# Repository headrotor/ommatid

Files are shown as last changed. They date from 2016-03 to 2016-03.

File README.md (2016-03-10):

# ommatid

Code and design files for my Ommatid spherical display/sensor array. 

* Here's an [Instructable about the enclosure and dome fabrication](http://www.instructables.com/id/Ommatid-Spherical-Display-constructing-the-enclosu/)
* Here's an [Instructable about the electronics and software](http://www.instructables.com/id/Ommatid-Spherical-Display-Electronics-Programming-/)

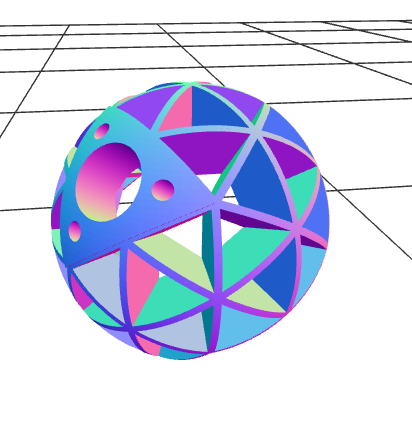
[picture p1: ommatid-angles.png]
cad rendering of sphere bottom section Ommatid CAD


Here are the construction and code files:

* `cad` -- 3D cad files. Likely not so useful unless you have access to a Stratasys Objet 
* `PCB` -- Schematic and printed circuit board design files
* `firmware` -- C code for ATTiny firmware for PCBs
* `code` -- host code (Python) for Ommatid.
* `sim` -- simulator, in [processing.org](http://processing.org) Python environment

NB: code is still very much a work in progress!

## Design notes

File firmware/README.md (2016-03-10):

# ommatid -- CAD files

Firmware for the Ommatid spherical display/sensor array. 

* Here's an [Instructable about the enclosure and dome fabrication](http://www.instructables.com/id/Ommatid-Spherical-Display-constructing-the-enclosu/)
* Here's an [Instructable about the electronics and software](http://www.instructables.com/id/Ommatid-Spherical-Display-Electronics-Programming-/)

This is C code designed to be executed on the 19 triangular boards inside the Ommatid. Each board has an ATTiny microcontroller, four independent IR LEDs and corresponding IR photodarlingtons (to sense reflected IR), and four WS2812B RGB LEDs. Note the RGB LEDs are not controlled or even connected to,  the ATTtiny).

All 19 boards are connected to the same RS-485 serial line at 250000
baud. Boards communicate with the host using a "speak only when spoken
to" protocol to eliminate bus contention.  Each board has an address
and will respond only to serial commands where it has been
specifically addressed. Addresses are one-byte ASCII characters from
a-o inclusive.

Serial protocol documentation: forthcoming!

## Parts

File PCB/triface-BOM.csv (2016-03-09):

Part | "Value" | "Device" | "Package" | "Description" | "COLOR" | "TP_SIGNAL_NAME"
+5V | "TEMT1020" | "TEMT1020" | "TEMT1020" | "" | "" | ""
C1 | "10uF" | "C-EUC0805" | "C0805" | "CAPACITOR | European symbol" | "" | ""
C2 | "10uF" | "C-EUC0805" | "C0805" | "CAPACITOR | European symbol" | "" | ""
C3 | "10uF" | "C-EUC0805" | "C0805" | "CAPACITOR | European symbol" | "" | ""
CX0 | "22pF" | "C-EUC0603" | "C0603" | "CAPACITOR | European symbol" | "" | ""
CX1 | "22pF" | "C-EUC0603" | "C0603" | "CAPACITOR | European symbol" | "" | ""
IC1 | "75ALS176AD" | "75ALS176AD" | "SO-08" | "DIFFERENTIAL BUS TRANSCEIVERS" | "" | ""
L1 | "WS2812B" | "WS2812B" | "WS2812B" | "" | "" | ""
L2 | "WS2812B" | "WS2812B" | "WS2812B" | "" | "" | ""
L3 | "WS2812B" | "WS2812B" | "WS2812B" | "" | "" | ""
L4 | "WS2812B" | "WS2812B" | "WS2812B" | "" | "" | ""
LED1 | "LG_T679-E1F1-1" | "LG_T679-E1F1-1" | "PLCC2" | "LC TOPLED® Low Current LED" | "green" | ""
LED2 | "LG_T679-E1F1-1" | "LG_T679-E1F1-1" | "PLCC2" | "LC TOPLED® Low Current LED" | "green" | ""
LED3 | "" | "LED0603" | "LED-0603" | "LEDs" | "" | ""
LED4 | "LG_T679-E1F1-1" | "LG_T679-E1F1-1" | "PLCC2" | "LC TOPLED® Low Current LED" | "green" | ""
LED5 | "LG_T679-E1F1-1" | "LG_T679-E1F1-1" | "PLCC2" | "LC TOPLED® Low Current LED" | "green" | ""
Q1 | "" | "MOSFET-NREFLOW" | "SOT23" | "N-Channel Mosfet" | "" | ""
Q2 | "" | "MOSFET-NREFLOW" | "SOT23" | "N-Channel Mosfet" | "" | ""
Q3 | "" | "MOSFET-NREFLOW" | "SOT23" | "N-Channel Mosfet" | "" | ""
Q4 | "" | "MOSFET-NREFLOW" | "SOT23" | "N-Channel Mosfet" | "" | ""
R1 | "2.2K" | "R-US_R0603" | "R0603" | "RESISTOR | American symbol" | "" | ""
R2 | "100" | "R-US_R0805" | "R0805" | "RESISTOR | American symbol" | "" | ""
R3 | "100" | "R-US_R0805" | "R0805" | "RESISTOR | American symbol" | "" | ""
R4 | "2.2K" | "R-US_R0603" | "R0603" | "RESISTOR | American symbol" | "" | ""
R5 | "2.2K" | "R-US_R0603" | "R0603" | "RESISTOR | American symbol" | "" | ""
R6 | "2.2K" | "R-US_R0603" | "R0603" | "RESISTOR | American symbol" | "" | ""
R7 | "330" | "R-US_R0603" | "R0603" | "RESISTOR | American symbol" | "" | ""
RLED1 | "330" | "RESISTOR0603-RES" | "0603-RES" | "Resistor" | "" | ""
T1 | "TEMT1020" | "TEMT1020" | "TEMT1020" | "" | "" | ""
T2 | "TEMT1020" | "TEMT1020" | "TEMT1020" | "" | "" | ""
T3 | "TEMT1020" | "TEMT1020" | "TEMT1020" | "" | "" | ""
U$1 | "ATTINY1634" | "ATTINY1634" | "SOIC20" | "" | "" | ""
Y1 | "12MHz" | "CRYSTAL5X3" | "CRYSTAL-SMD-5X3" | "Various standard crystals. Proven footprints. Spark Fun Electronics SKU : COM-00534" | "" | ""

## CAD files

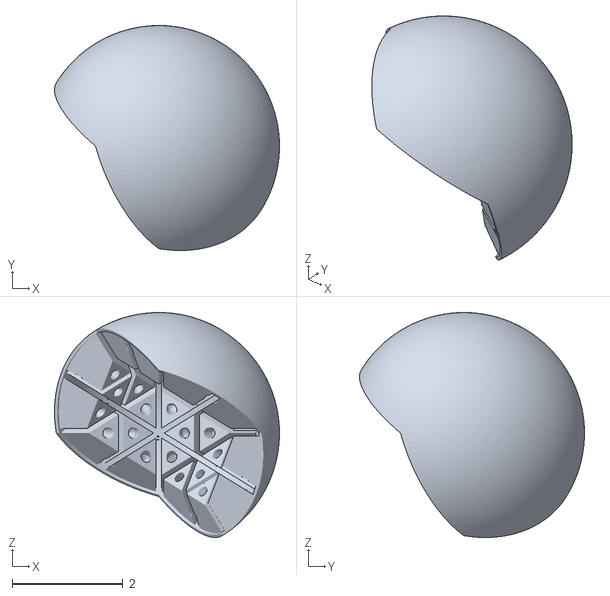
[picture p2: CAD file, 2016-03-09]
cad/top_dome_trans_2.stl
4.06 x 4.06 x 4.06

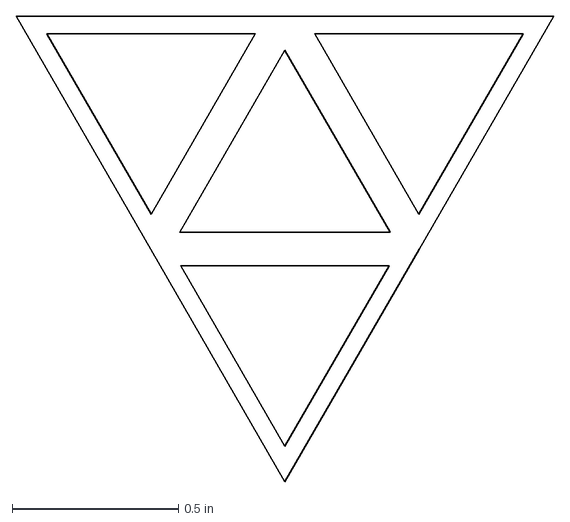
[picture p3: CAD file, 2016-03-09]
PCB/interiorface.dxf
1.62 x 1.40 in

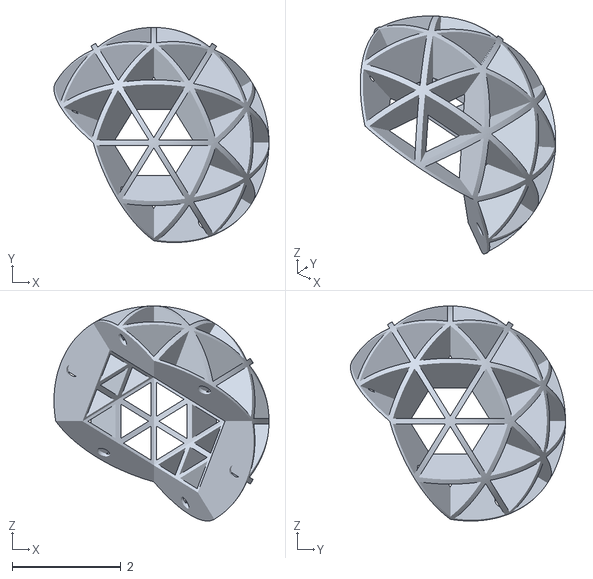
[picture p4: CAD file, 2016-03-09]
cad/top_dome_opaque_2.stl
3.95 x 3.95 x 3.95

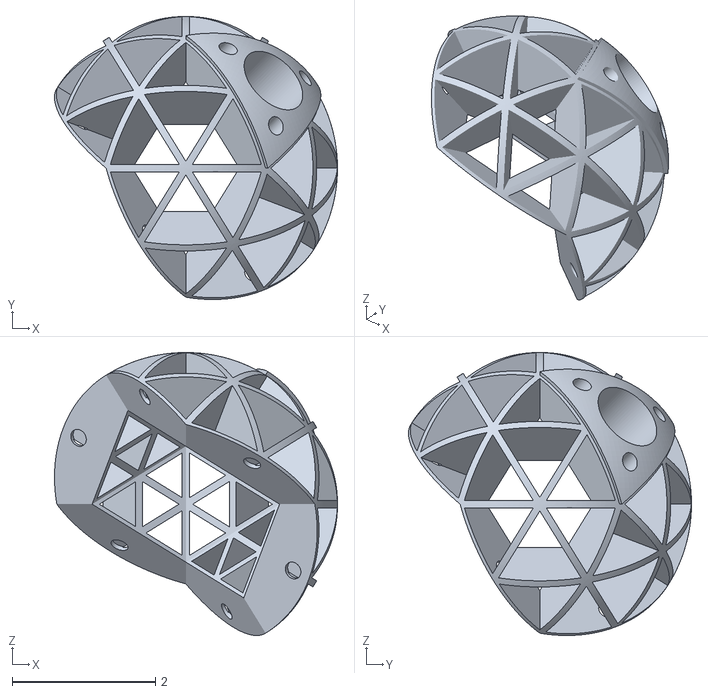
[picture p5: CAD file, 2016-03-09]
cad/bottom_dome_opaque_2.stl
3.95 x 3.95 x 3.95

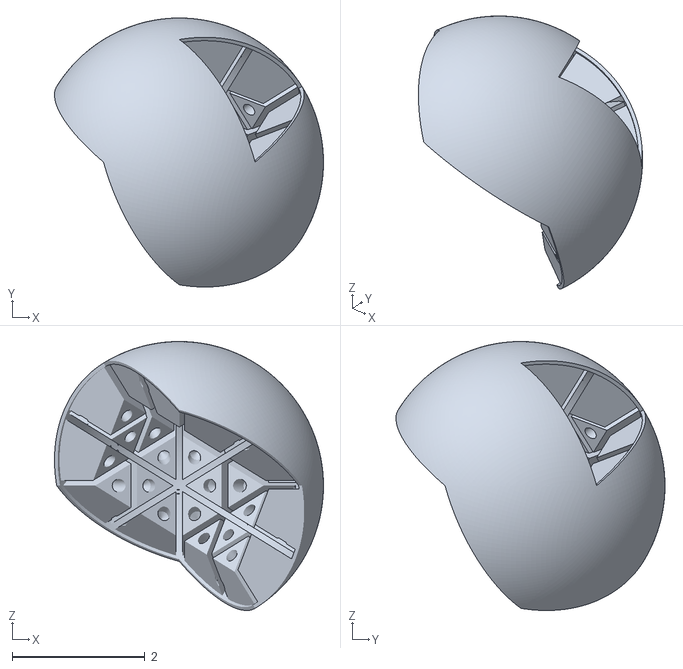
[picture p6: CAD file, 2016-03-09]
cad/bottom_dome_trans_2.stl
4.06 x 4.06 x 4.06

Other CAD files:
cad/sect_bottom/ommatid-trans.ipt
cad/sect_bottom/ommatid.ipt
cad/sect_bottom/trans-asm-bottom.iam
cad/sect_interior/ommatid-trans.ipt
cad/sect_interior/ommatid.ipt
cad/sect_interior/trans-asm-interior.iam
cad/sect_perf/ommatid-trans.ipt
cad/sect_perf/ommatid.ipt
cad/sect_perf/trans-asm-perf.iam

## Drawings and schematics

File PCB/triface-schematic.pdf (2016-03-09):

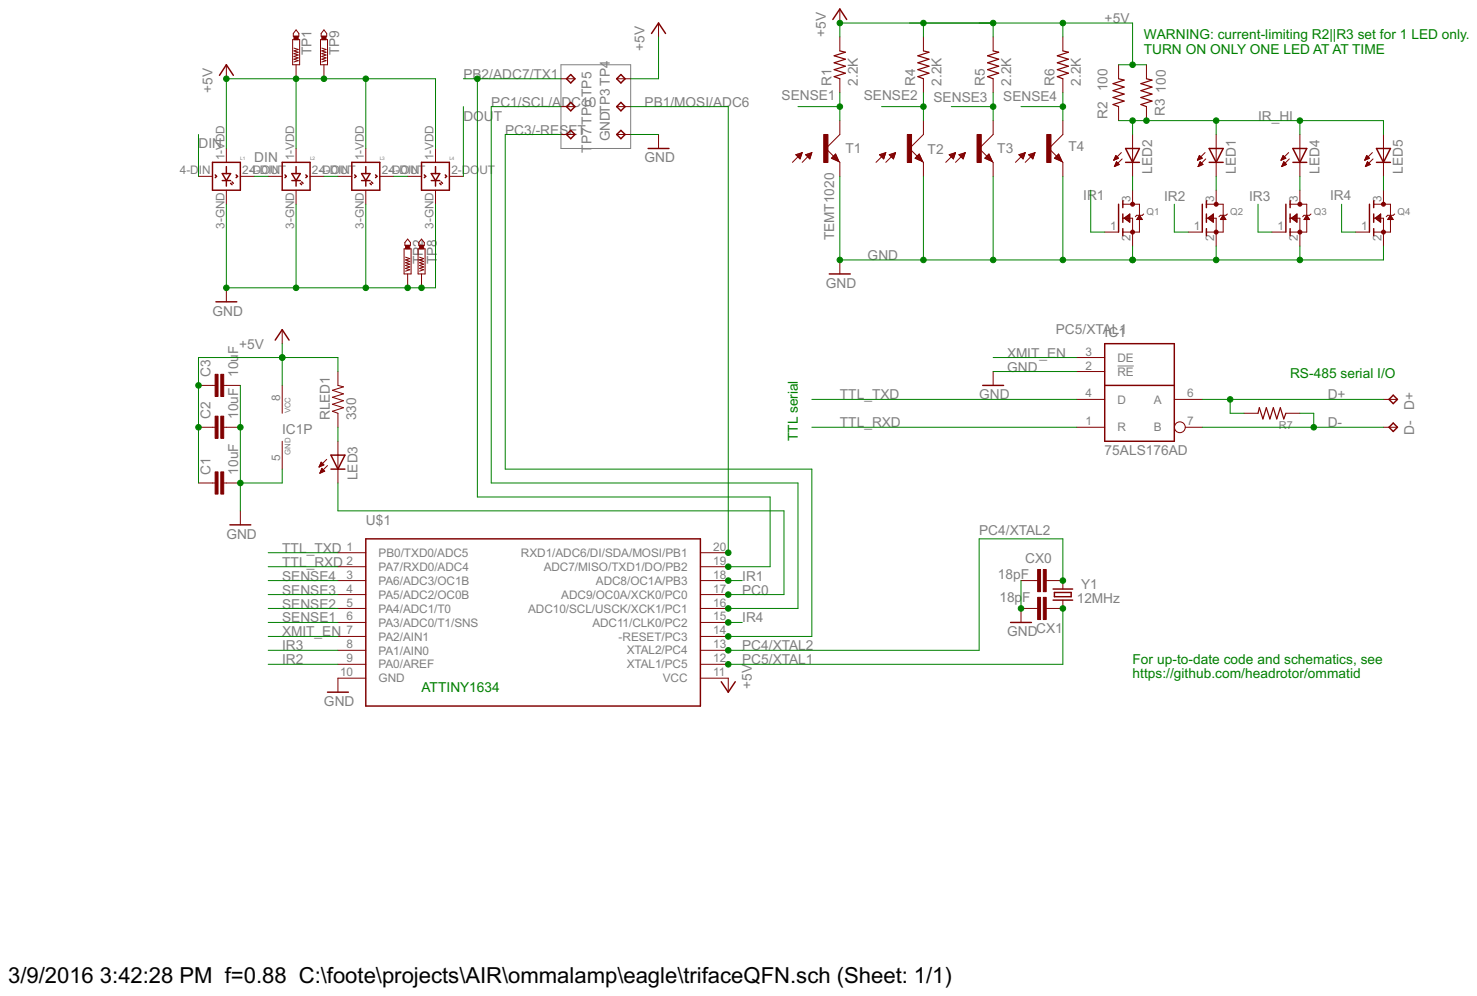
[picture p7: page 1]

WARNING: current-limiting R2||R3 set for 1 LED only. TURN ON ONLY ONE LED AT AT TIME

For up-to-date code and schematics, see
https://github.com/headrotor/ommatid

3/9/2016 3:42:28 PM f=0.88 C:\foote\projects\AIR\ommalamp\eagle\trifaceQFN.sch (Sheet: 1/1)

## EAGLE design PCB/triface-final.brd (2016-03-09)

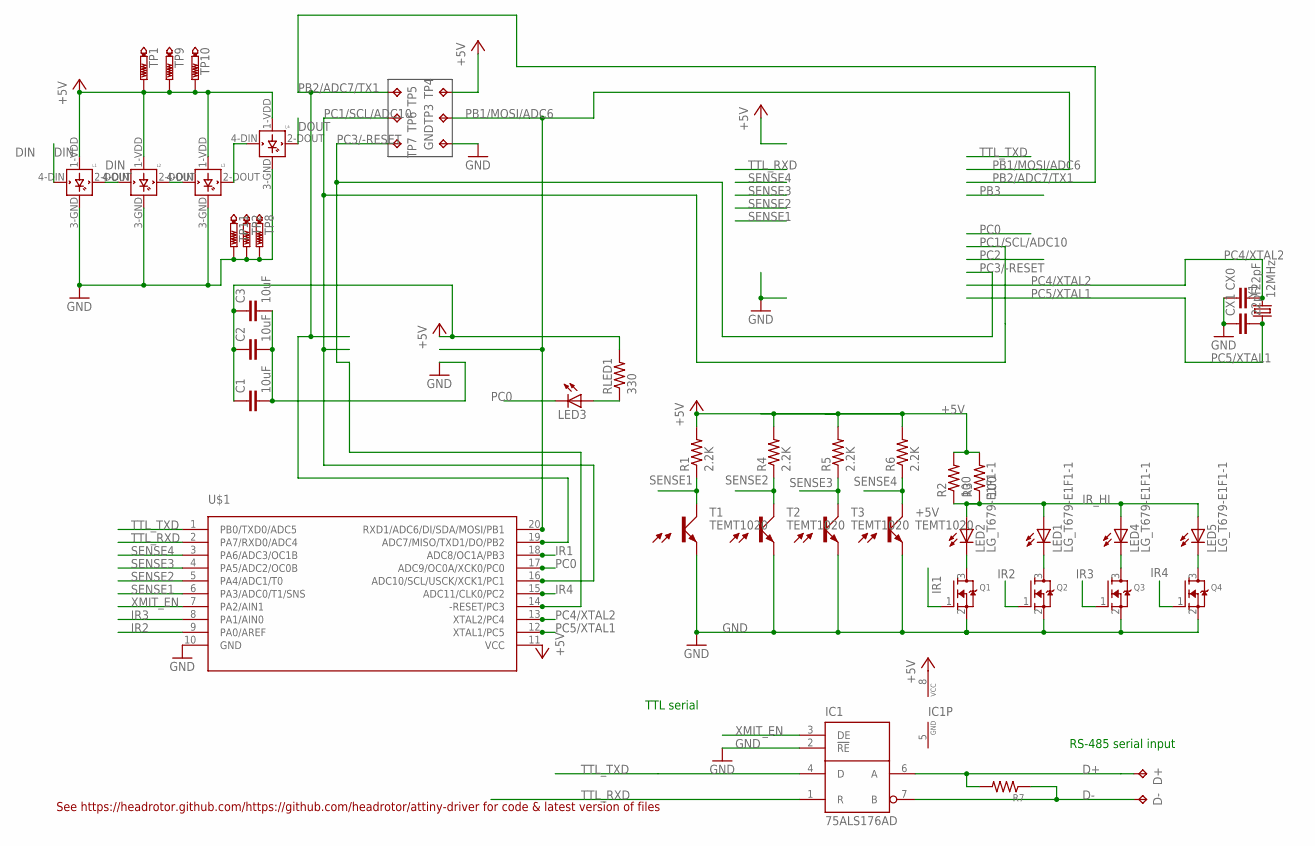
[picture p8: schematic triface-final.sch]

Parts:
+5V: TEMT1020
C1, C2, C3: 10uF; C0805
CX0, CX1: 22pF; C0603
D+: TPTP14R; TP14R
D-: TPTP14SQ; TP14SQ
GND: TPTP12SQ; TP12SQ
IC1: 75ALS176AD; SO-08
L1, L2, L3, L4: WS2812B
LED1, LED2, LED4, LED5: LG_T679-E1F1-1; PLCC2
LED3: LED0603; LED-0603
Q1, Q2, Q3, Q4: MOSFET-NREFLOW; SOT23
R1, R4, R5, R6: 2.2K; R0603
R2, R3: 100; R0805
R7: 330; R0603
RLED1: 330; 0603-RES
T1, T2, T3: TEMT1020
TP1, TP9, TP10: PTR1TP14SQ; TP14SQ
TP2, TP8, TP11: PTR1B2,54; B2,54
TP3, TP4, TP5, TP6, TP7: TPTP12R; TP12R
U$1: ATTINY1634; SOIC20
Y1: 12MHz; CRYSTAL-SMD-5X3

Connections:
+5V: C1.1, C2.1, C3.1, IC1.8 (VCC), L1.1-VDD (VDD), L2.1-VDD (VDD), L3.1-VDD (VDD), L4.1-VDD (VDD), R1.2, R2.2, R3.2, R4.2, R5.2, R6.2, RLED1.2, TP1.TP, TP4.TP, TP9.TP, TP10.TP, U$1.11 (VCC)
D+: D+.TP, IC1.6 (A), R7.2
D-: D-.TP, IC1.7 (B), R7.1
DIN: L1.4-DIN (DIN)
DOUT: L4.2-DOUT (DOUT)
GND: +5V.E, C1.2, C2.2, C3.2, CX0.1, CX1.1, GND.TP, IC1.2 (!RE), IC1.5 (GND), L1.3-GND (GND), L2.3-GND (GND), L3.3-GND (GND), L4.3-GND (GND), Q1.2 (S), Q2.2 (S), Q3.2 (S), Q4.2 (S), T1.E, T2.E, T3.E, TP2.TP, TP8.TP, TP11.TP, U$1.10 (GND)
IR1: Q1.1 (G), U$1.18 (ADC8/OC1A/PB3)
IR2: Q2.1 (G), U$1.9 (PA0/AREF)
IR3: Q3.1 (G), U$1.8 (PA1/AIN0)
IR4: Q4.1 (G), U$1.15 (ADC11/CLK0/PC2)
IR_HI: LED1.A, LED2.A, LED4.A, LED5.A, R2.1, R3.1
unnamed: LED2.C, Q1.3 (D)
unnamed: LED1.C, Q2.3 (D)
unnamed: L1.2-DOUT (DOUT), L2.4-DIN (DIN)
unnamed: LED3.A, RLED1.1
unnamed: L2.2-DOUT (DOUT), L3.4-DIN (DIN)
unnamed: L3.2-DOUT (DOUT), L4.4-DIN (DIN)
unnamed: LED4.C, Q3.3 (D)
unnamed: LED5.C, Q4.3 (D)
PB1/MOSI/ADC6: TP3.TP, U$1.20 (RXD1/ADC6/DI/SDA/MOSI/PB1)
PB2/ADC7/TX1: TP5.TP, U$1.19 (ADC7/MISO/TXD1/DO/PB2)
PC0: LED3.C, U$1.17 (ADC9/OC0A/XCK0/PC0)
PC1/SCL/ADC10: TP6.TP, U$1.16 (ADC10/SCL/USCK/XCK1/PC1)
PC3/-RESET: TP7.TP, U$1.14 (-RESET/PC3)
PC4/XTAL2: CX0.2, U$1.13 (XTAL2/PC4), Y1.3 (2)
PC5/XTAL1: CX1.2, U$1.12 (XTAL1/PC5), Y1.1
SENSE1: R1.1, T1.C, U$1.6 (PA3/ADC0/T1/SNS)
SENSE2: R4.1, T2.C, U$1.5 (PA4/ADC1/T0)
SENSE3: R5.1, T3.C, U$1.4 (PA5/ADC2/OC0B)
SENSE4: +5V.C, R6.1, U$1.3 (PA6/ADC3/OC1B)
TTL_RXD: IC1.1 (R), U$1.2 (PA7/RXD0/ADC4)
TTL_TXD: IC1.4 (D), U$1.1 (PB0/TXD0/ADC5)
XMIT_EN: IC1.3 (DE), U$1.7 (PA2/AIN1)

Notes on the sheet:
TTL serial
RS-485 serial input
See https://headrotor.github.com/https://github.com/headrotor/attiny-driver for code & latest version of files

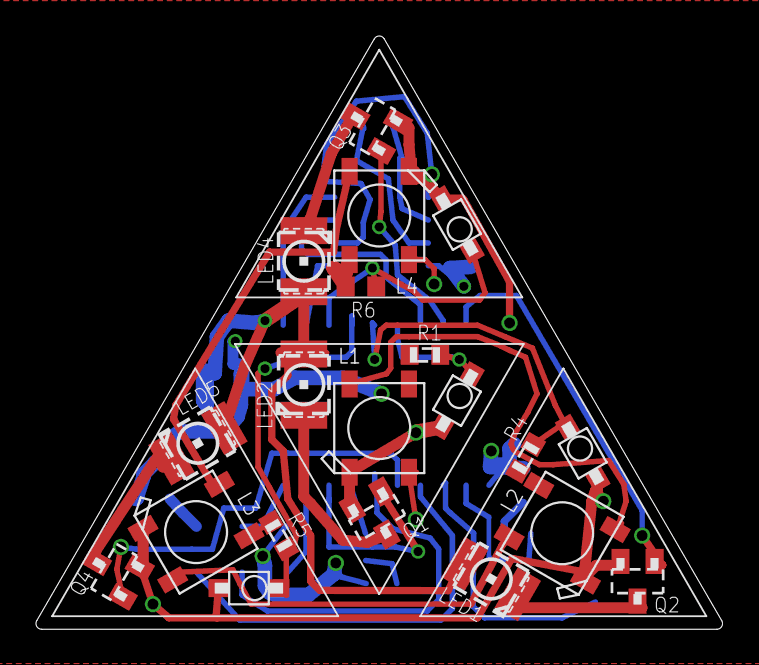
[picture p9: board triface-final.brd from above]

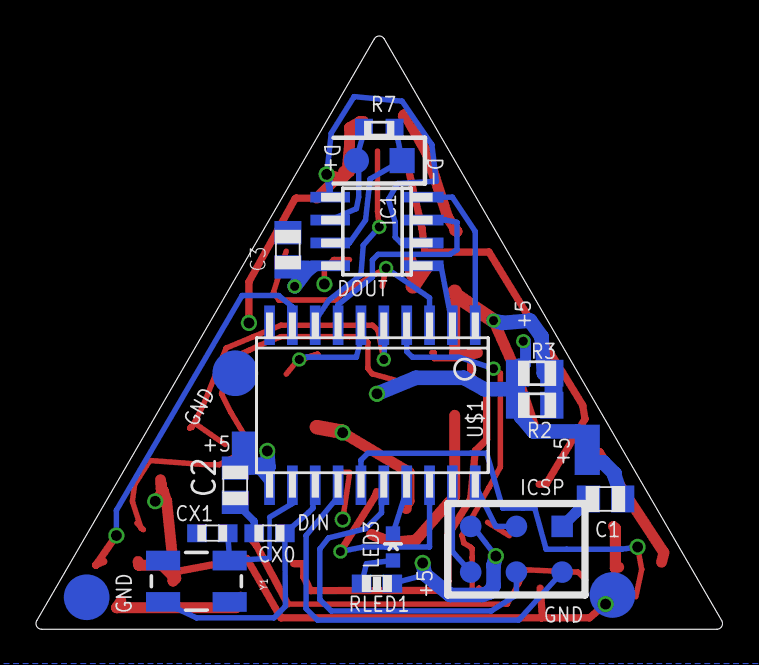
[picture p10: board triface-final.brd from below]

Board: 2 copper layers, 38.1 x 33.0 mm, 47 parts (27 on the bottom side), 31 nets.

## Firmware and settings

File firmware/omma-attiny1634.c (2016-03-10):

/*
 * omma_attiny1634.c
 *
 * Created: 8/12/2015 5:23:07 PM
 *  Author: foote
 */ 

#include <avr/io.h>

#define F_CPU 12000000 // 12 MHz

// addressing: top 10  a-bcd-efg-hij
//           bottom 9    klm-nop-qrs

#define ADDRESS 'e'


/*


a: .		k: --.
b: ..		l: --..
c: ...		m: --...
d: ....		n: --....
e: -		o: ---
f: -.		p: ---.
g: -..		q: ---..
h: -...		r: ---...
i: -....	s: ---....
j: --		(t: ----)
*/

/* FUSES
BODACT = BOD_DISABLED
SELFPRGEN = [ ]
RSTDISBL = [ ]
DWEN = [ ]
SPIEN = [X]
WDTON = [ ]
EESAVE = [ ]
BODLEVEL = 4V3
CKDIV8 = [ ]
CKOUT = [ ]
SUT_CKSEL = EXTXOSC_8MHZ_XX_16KCK_16CK_16MS

EXTENDED = 0xFF (valid)
HIGH = 0xDC (valid)
LOW = 0xEF (valid)
*/


// This is the address of the AVR on the RS-485 bus. Every one should be different!
// Address is one byte: a a-j for 20-unit sphere
uint8_t addr = ADDRESS;  //this is a char, not a number!
// number of times to blink, 1 for 'a', 2 for 'b', etc. 
uint8_t blink_address = ADDRESS - 'a' + 1;

#include <avr/io.h>
#include <avr/interrupt.h>
#include <avr/sleep.h>
#include <util/delay.h>
#include "setup.c"
#include "1634_UART.h"

// ATtiny1634 Pin map
//
//              +-\/-+
//   TXD  PB0  1|o   |20  PB1 MOSI
//   RXD  PA7  2|    |19  PB2 MISO
//        PA6  3|    |18  PB3
//        PA5  4|    |17  PC0
//        PA4  5|    |16  PC1 SCK
//        PA3  6|    |15  PC2
//XMIT_EN PA2  7|    |14  PC3 RESET
//        PA1  8|    |13  PC4
//        PA0  9|    |12  PC5
//        GND 10|    |11  VCC


// indicator LED on PC0
#define LED_C0 PC0

// Turn off all IR leds. To avoid overcurrent, ONLY ONE IR SHOULD BE ON AT A TIME

// IRLED 1: LED2 PB3 (center)
#define IRLED_B3 PB3
// IRLED 2: PA0
#define IRLED_A0 PA0
// IRLED 3: PC2
#define IRLED_C2 PC2
// IRLED 4: PA1
#define IRLED_A1 PA1


/// ADC stuff. ADCs are
// IR sensor 0: PA3-ADC0
// IR sensor 1: PA4-ADC1
// IR sensor 2: PA5-ADC2
// IR sensor 3: PA6-ADC3


// define buffers for averaging. 
// max length, Actual length is dynamic
#define MAX_BUFFER 64

// length of on and off buffers
volatile uint8_t off_buff = 4;
volatile uint8_t on_buff = 4;

// raw ADC response when IR led is unlit
volatile uint8_t sense_off[4*MAX_BUFFER];
// index into off buffer
volatile uint8_t offptr = 0;

// raw ADC response when IR led is unlit
volatile uint8_t sense_on[4*MAX_BUFFER];
// index into off buffer
volatile uint8_t onptr = 0;

// when true, trigger IR sensing in ADC interrupt. 
volatile uint8_t autosense = 0; 

// Raw ADC response when IR led is lit
volatile uint8_t  lit = -1;
volatile uint8_t  adc_ptr = 0;


#define TXD0 PB0


#define MAX_COMMAND_LENGTH 24
unsigned char command_str[MAX_COMMAND_LENGTH];
unsigned char command_len = 0;


void put_hex(uint8_t number) {
	unsigned char c;
	c = ((number >> 4) & 0x0F);
	if (c > 9)
	    USART_send_byte(c -10 + 'A');
	else
	    USART_send_byte(c + '0');
	c = number & 0x0F;
	if (c > 9)
	   USART_send_byte(c - 10 + 'A');
	else
	   USART_send_byte(c + '0');
}


void init_ADC(void){
	adc_ptr = 0;

	ADMUX = 0;		//Select 5V internal reference and channel 0

	// not free running, use conversion complete interrupt, 128x clock division
	ADCSRA = (1<<ADEN) | (1<<ADIE) | (1<<ADPS2) | (1<<ADPS1) | (1<<ADPS0);
	ADCSRA = (1<<ADEN) | (1<<ADIE) | (1<<ADPS2) |  (1<<ADPS1);

	//ADLAR: right-shft so MSB values in ADCH (ignore ADCL)
	ADCSRB = (1<<ADLAR)  ;

	// Disable digital inputs on ADC0-ADC3
	DIDR0 = (1<<ADC3D) |(1<<ADC2D) |(1<<ADC1D) |(1<<ADC0D);

	ADCSRA |= (1<<ADSC); //init thing and start Conversion
}

void reset_buffers(){
	// clear all buffers
	uint8_t i;
	onptr = 0;
	offptr = 0;
	for (i=0; i<MAX_BUFFER; i++){
		sense_off[i] = 0;
		sense_on[i] = 0;
	}
}


// Setup the ATtiny
void setup(void) {
	
	// Set input/outputs
	DDRC |= (1<<LED_C0) | (1<<IRLED_C2);
	DDRB |= (1<<IRLED_B3) | (1<<TXD0);
	DDRA |=	(1<<IRLED_A0) | (1<<IRLED_A1) | (1<<XMIT_EN);

	// set initial values
	// All IRLEDs OFF, XMIT_EN LOW
	PORTC &= ~((1<<LED_C0) | (1<<IRLED_C2));
	PORTB &= ~(1<<IRLED_B3);
	PORTA &= ~((1<<IRLED_A0) | (1<<IRLED_A1) | (1<<XMIT_EN));

   // initialize serial port on USART0:
   	USART_init0(250000L);
	reset_buffers();

	// Init ADC
	init_ADC();
	
	sei(); // Turn on interrupts
}




/* serial protocol is ASCII hex bytes delimited by '<' and '>'
Address is first byte, for readability 0-9 and a-j
second byte is opcode:
x -- turn off all LEDs
y -- turn on red LED
0,1,2,3, -- turn on IR led 0,1,2,3

f -- return value of 4 off sensors
o -- return value of 4 sensors with LED on
q - read all 4 IR sensors, normalized by subtracting average of other 3 non-illuminated (returns quad ASCII byte)
r -- read all 4 IR sensors normalized by subtracting average of self non-illuminated
s -- set autosense
w -- write address (volatile)

third and following bytes are data if any

*/

void send_sensor_response_r(void){
	// Send the sensor response back to host over the serial line
	int i, j, temp;
	int sum_off = 0;
	int sum_on = 0;
	USART_send_byte('<');

	// send upper-case address in response so we don't address something else on the bus!
	//	put_hex(sense[0]);
	//	put_hex(sense[1]);
	//	put_hex(sense[2]);
	//	put_hex(sense[3]);
	// send upper-case address in response so we don't address something else on the bus!
	USART_send_byte(ADDRESS - 'a' + 'A');

	for (i=0; i<4; i++){
		sum_on = 0;
		sum_off = 0;
		for (j=0; j<off_buff; j++){
			sum_off += sense_off[i*off_buff + j];
		}
		for (j=0; j<on_buff; j++){
			sum_on += sense_on[i*on_buff + j];
		}
		temp = (sum_off/off_buff) - (sum_on/on_buff);
		if (temp < 0)
			temp = 0;
		if (temp > 255)
			temp = 255;
		put_hex((uint8_t)temp);
	}
	USART_send_byte('>');
	//USART_send_byte('\n');

}

void send_sensor_response_q(void){
	// Send the sensor response back to host over the serial line
	// in this version, subtract the off sensor for other channels from from the on sensor value for this channel
	int i, j, temp;
	//int sum_off[] = {0, 0, 0, 0};
	int sum_off = 0;
	int sum_on = 0;
	USART_send_byte('<');

	// send upper-case address in response so we don't address something else on the bus!
	USART_send_byte(ADDRESS - 'a' + 'A');

	sum_off = 0;
	for (i=0; i<4; i++){
		for (j=0; j<off_buff; j++){
			sum_off += sense_off[i*off_buff + j];
		}
	}	

	sum_off = sum_off / (4*off_buff);
	//sum_off = 255;
	
	for (i=0; i<4; i++){
		sum_on = 0;
		for (j=0; j<on_buff; j++){
			sum_on += sense_on[i*on_buff + j];
		}
		temp = sum_off - (sum_on/on_buff);
		if (temp < 0)
		 temp = 0;
		if (temp > 255)
		temp = 255;
		put_hex((uint8_t)temp);
	}
	USART_send_byte('>');
	//USART_send_byte('\n');

}

uint8_t a2int8(unsigned char c[]){
	// el cheapo 8-bit atoi, string
	return (((c[0] - '0')*10) + c[1] - '0');
}

void send_on_response(void){
	// Send the averaged on response from each sensor
	int i, j;
	int sum_on = 0;
	USART_send_byte('<');

	USART_send_byte(ADDRESS - 'a' + 'A');
//	USART_send_byte('o');

	for (i=0; i<4; i++){
		sum_on = 0;
		for (j=0; j<on_buff; j++){
			sum_on += sense_on[i*on_buff + j];
		}
		put_hex((uint8_t)(sum_on/on_buff));
	}
	USART_send_byte('>');
	//USART_send_byte('\n');

}
void send_off_response(void){
	// Send the averaged on response from each sensor
	int i, j;
	int sum_off = 0;

	USART_send_byte('<');
	USART_send_byte(ADDRESS - 'a' + 'A');

//	USART_send_byte('f');

	for (i=0; i<4; i++){
		sum_off = 0;
		for (j=0; j<on_buff; j++){
			sum_off += sense_off[i*off_buff + j];
		}
		put_hex((uint8_t)(sum_off/off_buff));
	}
	USART_send_byte('>');
}


void set_off_buffer_length(uint8_t new_off){
	// set the buffer length
	// first clear all the buffers
	if (new_off > MAX_BUFFER){
		new_off = MAX_BUFFER;
	}
	off_buff = new_off;
	reset_buffers();
}

void set_on_buffer_length(uint8_t new_on){
	// set the buffer length
	// first clear all the buffers
	if (new_on > MAX_BUFFER){
		new_on = MAX_BUFFER;
	}
	on_buff = new_on;
	reset_buffers();
}

void all_leds_off(void){
	// Turn off all IR leds. To avoid overcurrent, ONLY ONE IR SHOULD BE ON AT A TIME
	PORTC &= ~(1<<IRLED_C2);
	PORTB &= ~(1<<IRLED_B3);
	PORTA &= ~((1<<IRLED_A0) | (1<<IRLED_A1));
}

void parse_command(void){
	// if we are here there is a valid serial command in command_str
	// with length in command_len
	// zeroth char will be a '<'
	if (command_len >=3) {
		// first char is the address. If it's not ours, ignore
		if (command_str[1] != ADDRESS) 
			return;

		// Turn on LED
		PORTC &= ~(1<<LED_C0);
		switch(command_str[2]){

		case  'y':
			// turn on red led
			PORTC &= ~(1<<LED_C0);
			//USART_send_byte('x');
			break;

		case  'x':
			// turn off all LEDs
			PORTC |= (1<<LED_C0);
			all_leds_off();
			lit = 0;
			break;

		case  'q':
		send_sensor_response_q();
		break;

		case  'r':
		send_sensor_response_r();
		break;

		case 'O':
		// set off buffer length
		set_off_buffer_length(a2int8(command_str + 3));
		break;

		case 'F':
		// set off buffer length
		set_on_buffer_length(a2int8(command_str + 3));
		break;
		
		case 'b':
		// return buffer status for debugging
		put_hex(on_buff);
		put_hex(off_buff);
		break;

		case  's':
		// start conversion
		send_sensor_response_q();
		offptr = 0;
		onptr = 0;
		adc_ptr = 0;
		PORTC &= ~(1<<LED_C0);
		break;
		
		case  'c':
		// start conversion and send response from last conversion
		send_sensor_response_r();
		offptr = 0;
		onptr = 0;
		adc_ptr = 0;
		PORTC &= ~(1<<LED_C0);
		break;

		case  'o':
		send_on_response();
		break;

		case  'f':
		send_off_response();
		break;
		}

		// Turn off LED
		PORTC |= (1<<LED_C0);

	}
}




uint8_t accumulate_command_string(uint8_t c){ // ... and add to command string
// --------------------------------------------------------------------------
// process incoming chars - commands start with '<' and end with '>'
// return 1 if command string is complete - else return zero

	/* catch beginning of this string */
	if (c == '<') { // this will catch re-starts and stalls as well as valid commands.
		command_len = 0;
		command_str[command_len++] = c;
		return 0;
	}
	
	if (command_len != 0){	 // string in progress, accumulate next char
		
		if (command_len < MAX_COMMAND_LENGTH)
		command_str[command_len++] = c;
		return (c == '>');
	}
	return 0;
}


#ifdef FOO
// Quasi-free-running ADC, step through 4 ADC channels sequentially
ISR(ADC_READY_vect)
{

	if (lit == adc_ptr) // If there's an LED lit, store the value here
	sense_on[adc_ptr] = ADCH;	// Read ADC
	else // otherwise store the value here
	sense_off[adc_ptr] = ADCH;	// Read ADC


	if (++adc_ptr >= 4) adc_ptr = 0;
	// select next channel
	ADMUX = adc_ptr;
	ADCSRA |= (1<<ADSC);
	
	// for debug: turn on LED so we know we're here
	//PORTC &= ~(1<<LED);

}

// Quasi-free-running ADC, step through 4 ADC channels sequentially
ISR(ADC_READY_vect)
{

	if (lit == adc_ptr){ // If there's an LED lit, store the value here
		sense_on[adc_ptr*ON_BUFF + onptr++] = ADCH;	// Read ADC
		if (onptr >= ON_BUFF) onptr = 0;
	}
	else { // otherwise store the value here
		sense_off[adc_ptr*OFF_BUFF + offptr++] = ADCH; //Read ADC
		if (offptr >= OFF_BUFF) offptr = 0;
	}
	
	if (++adc_ptr >= 4) adc_ptr = 0;
	// select next channel
	ADMUX = adc_ptr;
	ADCSRA |= (1<<ADSC);
	
	// for debug: turn on LED so we know we're here
	//PORTC &= ~(1<<LED);

}

#endif

// Quasi-free-running ADC, step through 4 ADC channels sequentially
ISR(ADC_READY_vect)
{

	// adc pointer auto-increments, if it's less than 4 turn on LED
	if (adc_ptr < 4 ){ 
		sense_on[adc_ptr*on_buff + onptr++] = ADCH;	// Read ADC
		if (onptr >= on_buff){ 
			// keep sampling with IR on for ON_BUFF samples
			adc_ptr++;
			onptr = 0;
		}
	}
	else if (adc_ptr < 8) { // otherwise store the value here
		sense_off[(adc_ptr-4)*off_buff + offptr++] = ADCH; //Read ADC
		if (offptr >= off_buff){ 
			// keep sampling with IR off for OFF_BUFF samples
			adc_ptr++;
			offptr = 0;
		}
	}
	
	// uncomment to autorun, else trigger capture by adc_ptr =0
	// select next channel
	//if (adc_ptr >= 8){
	//	adc_ptr = 0;
	//}

	if(1){
		switch(adc_ptr){
			case 0:
			// turn on corresponding IR
			PORTB |= (1<<IRLED_B3);
			break;

			case  1:
			// turn on LED 2 -- East
			PORTA |= (1<<IRLED_A0);
			PORTB &= ~(1<<IRLED_B3);
			break;
			
			case  2:
			// turn on LED 3 -- West
			PORTC |= (1<<IRLED_C2);
			PORTA &= ~(1<<IRLED_A0);
			break;

			case  3: // turn on North (serial) LED
			PORTA |= (1<<IRLED_A1);
			PORTC &= ~(1<<IRLED_C2);
			break;

			default:
			PORTC &= ~(1<<IRLED_C2);
			PORTB &= ~(1<<IRLED_B3);
			PORTA &= ~((1<<IRLED_A0) | (1<<IRLED_A1));
			

		}
	}

	ADMUX = adc_ptr & 0x03;
	ADCSRA |= (1<<ADSC);

	// for debug: turn on LED so we know we're here
	//PORTC &= ~(1<<LED);
}


#define BLINK_MS 100

void wait_for_data(){
	// wait for data to show up in buffer. Blink address until it does
	uint8_t acount = blink_address;
	while(!USART_data_present()){
		acount = blink_address;		
		// long blinks for multiples of five, thus 16 = - - - .
		while (acount > 5) {
			PORTC &= ~(1<<LED_C0); // turn on
			_delay_ms(BLINK_MS);
			if (USART_data_present()) return;
			_delay_ms(BLINK_MS);
			if (USART_data_present()) return;
			_delay_ms(BLINK_MS);
			PORTC |= (1<<LED_C0); // turn off
			_delay_ms(BLINK_MS);
			if (USART_data_present()) return;
			acount -= 5;
			
		}
		while (acount > 0) {
			PORTC &= ~(1<<LED_C0); // turn on
			_delay_ms(BLINK_MS);
			if (USART_data_present()) return;
			PORTC |= (1<<LED_C0); // turn off
			_delay_ms(BLINK_MS);
			if (USART_data_present()) return;
			acount -= 1;
		}
		acount = 10;
		while (acount > 0) {
			PORTC |= (1<<LED_C0); // turn off
			_delay_ms(BLINK_MS);
			if (USART_data_present()) return;
			acount -= 1;
		}
	}	
	
}

/*****************************************************************************************************************************************/
int main(void) {
	setup();

	uint8_t cData;



	// turn off LED
	PORTC |= (1<<LED_C0);

	wait_for_data();
	while(1) {

        // Main parser loop starts here.
		if (USART_data_present()) { // check for waiting UART data from SPU
			cData = get_USART_buf_byte(); // get next char from ring buffer...
			if(0) USART_send_byte(cData);   /* echo char to serial out for debug does not work rs 485*/
			if(accumulate_command_string(cData)){ // ... and add to command string
				// if we are here we have a complete command; parse it
				parse_command(); // parse and execute commands
			}
			//_delay_ms(1);
		}

		if(0) {
				// blink LED for testing
		_delay_ms(250);
		PORTC &= ~(1<<LED_C0);
		_delay_ms(250);
		PORTC |= (1<<LED_C0);
	}
    
/*


		USART_Transmit0('A');
		//watchdog_sleep(T500MS);

		USART_Transmit0('b');

		_delay_ms(250);

*/	
	
	}
}

ISR(WDT_vect) { }

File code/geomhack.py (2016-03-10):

#!/usr/bin/python
# -*- coding: utf-8 -*-

"""
geomhack.py: first cut at using geometry from omma_geom

"""

import serial
import sys
import time
import math

import RPi.GPIO as GPIO
 
import opc

import colorsys
import random

#from omma_geom import Vertex as vert
from omma_geom import Ommatid


# while True:
# 	for i in range(numLEDs):
# 		pixels = [ (0,0,0) ] * numLEDs
# 		pixels[i] = (255, 255, 255)
# 		client.put_pixels(pixels)
# 		time.sleep(0.01)


_LIST_PORTS_OK = True

#try:  # this is only in python 2.6, and fails on some 64 machines
#    import serial.tools.list_ports
#except ImportError:
#    _LIST_PORTS_OK = False



class SerialError(Exception):
    """ custom exception for handing serial port errors"""
    def __init__(self, port="???", string="unknown"):
         self.port = port #offending serial port
         self.string = string #descriptive string
    def __str__(self):
         return repr("SerialError on port %s: %s" % (self.port,self.string))


class SerialIO(object):
    """serial_io: Wrapper for pyserial module"""
    def __init__(self, port, baudrate, timeout=0.1, echo=False, xonxoff=False ):

        self.port = port
        self.baudrate = baudrate
        self.timeout = timeout
        self.echo = echo
        self.stdout = False
        self.ser = None
        self.status = 'OK'
        self.reopen()

    def reopen(self,timeout=0.1, ser_args = {}):
        """ open or reopen the given port, additional args in ser_args dict """
        self.timeout = timeout
        # first close it if it's already open

        # do we want stdout (for debug)?
        if self.port == 'stdout':
            self.stdout = True
            self.ser = sys.stdout
            self.status = "OK"
            return

        if self.ser is not None:
            try:
                self.ser.close()
                self.ser = None
            except serial.SerialException, v:
                print repr(v)
                self.status = 'error'

        if True:
            try:  # xonxoff=True hoses binary polling of Faulhabers!
                self.ser = serial.Serial(self.port, self.baudrate,
                                         timeout=self.timeout, xonxoff=False,
                                         **ser_args)
            except serial.SerialException, v:
                self.status = 'error'
                print str(v)
            else:
                print str(self.ser)
        return self.status

    def really_flush_input(self):
        """ because ser.flushInput() doesn't seem to work :/"""
        if self.stdout:
            return
        #self.ser.flushInput()
        #time.sleep(0.01)
        readstr = ''
        incount = self.ser.inWaiting()
        #readstr += self.ser.read(incount)
        #incount = self.ser.inWaiting()
        while incount > 0:
            readstr += self.ser.read(incount)
            print '%d chars gobbled "%s"' % (incount,repr(readstr))
            time.sleep(0.01)
            incount = self.ser.inWaiting()

    def checkwrite(self, string, flush=True):
        """ write the given string to the serial device, raising errors """
        try:
            self.ser.write(string)
        except serial.serialutil.SerialTimeoutException as v:
            print str(v)
            raise SerialError(self.port,str(v))
        except serial.SerialException as v:
            print str(v)
            raise SerialError(self.port,str(v))
        if flush:
            if self.stdout:
                sys.stdout.flush()
            else:
                self.ser.flushOutput()

#    def read(self, nb):
#        return self.ser.read(nb)

    def checkread(self,n,where = ""):
        """returns string actually read, exception if error"""
        if self.stdout:
            return ""
        try:
            readstr = self.ser.read(n)
        except serial.SerialException as v:
            print str(v)
            raise SerialError(self.port,str(v))
        if len(readstr) != n:
            #print where + " err, got '%s'" % readstr
            raise SerialError(self.port,where + "truncated Response")
            return ""
        return (readstr)

    def readline_n(self,n):
        """Tries to read a line up to \n or \r or n chars."""
        incount = 0
        instr = ''
        looping = True
        while looping:
            try:
                char = self.ser.read(1)
            except serial.SerialException as v:
                raise SerialError(self.port, "readline read char error")
            instr += char
            incount += 1
            if incount >= n:
                return instr
            if char == '\n' or char == '\r':
                return instr

#     def saferead(self):
#         """returns string actually read, exception if error"""
#         if self.stdout:
#             return ""
# #        try:
#         readstr = self.ser.read()
# #        except serial.SerialException as v:
# #            print str(v)
# #            raise SerialError(self.port,str(v))
#         if len(readstr) != n:
#             print "err, got '%s'" % readstr
#             #raise SerialError(self.port,"No Response")
#             return ""
#         return (readstr)


def GetPortList(plist):
    """ return a list of available serial ports"""
    if len(plist) < 1:
        # if no list of portnames, make one
        plist = []
    OKports = []
    for port in plist:
        ser = None
        try:
            ser = serial.Serial(port, 9600)
        except serial.SerialException, v:
            pass
        else:
            OKports.append(ser.name)
        finally:
            if ser:
                ser.close()
    return OKports



def rangemap(val, thresh):
    """ map sensor range to pixel range"""
    if val < thresh:
        return 0
    val = val *15
    if val > 255:
        val = 255
    return val
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

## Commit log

2016-03-09 add PCB files
    [interiorface.dxf, triface-BOM.csv, triface-final.brd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]
2016-03-10 first add
    [ommatid-trans.ipt, ommatid.ipt, trans-asm-bottom.iam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]

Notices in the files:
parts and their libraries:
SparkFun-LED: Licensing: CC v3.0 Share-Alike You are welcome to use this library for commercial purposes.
